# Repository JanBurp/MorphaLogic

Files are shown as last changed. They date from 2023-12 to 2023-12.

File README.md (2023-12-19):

# MorphaLogic

An Eurorack module based around a Arduino Nano.

With AND, OR, XOR logic functions, a Flip Flip (Q), a Clock Divider mode, and more.

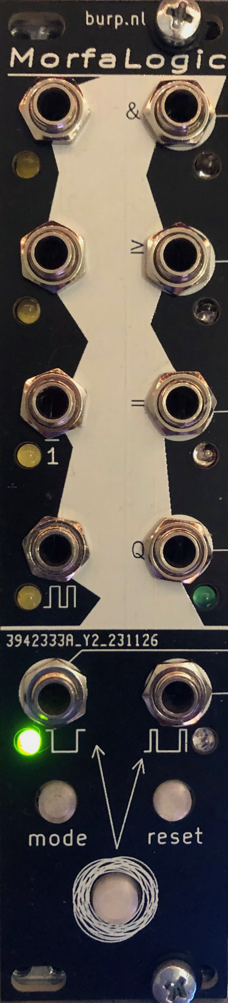
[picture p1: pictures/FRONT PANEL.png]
Morgalogic Front Panel


## Inputs, Outputs & Buttons

<table>
<tr>
<td><b>LEFT</b></td><td style="text-align: right;"><b>RIGHT</b></td>
    <tr><td>INPUT: input (A)</td><td style="text-align: right;">OUTPUT: AND (or clock / 16)</td></tr>
    <tr><td>INPUT: input (B)</td><td style="text-align: right;">OUTPUT: OR (or clock / 8)</td></tr>
    <tr><td>INPUT: Inverse (INV)</td><td style="text-align: right;">OUTPUT: XOR (or clock / 4)</td></tr>
    <tr><td>INPUT: Clock (CLK)</td><td style="text-align: right;">OUTPUT: Q - Flip Flop (or clock / 2)</td></tr>
    <tr><td>OUTPUT: Inverse of TRIG BUTTON</td><td style="text-align: right;">Trigger on press & release of TRIG BUTTON</td></tr>
    <tr><td>BUTTON: Mode button</td><td style="text-align: right;">BUTTON: Reset button</td></tr>
    <tr><td colspan="2" style="text-align: center;">TRIG BUTTON</td></tr>
</tr>
</table>

## Functions

### Logic functions

- Basic logic funcions AND, OR, XOR (using the first inputs on the left side).
- Flip Flop (Q) (first input will SET, second input will RESET).
- NOT input, or MODE button, to inverse all logic outputs (NAND, NOR, NXOR, NQ)
- CLOCK input, when present, all Logic outputs only are HIGH when CLOCK is HIGH
- RESET button to reset Q and CLOCK

### Trig button

When the TRIG button is pressed (and released):

- A LOW gate is send to the first (left) output. It will be HIGH when the button is not pressed.
- A short pulse is send to the second output on press & release of the button.
- If the module is in Clock Divider mode, the press & release time will set the Clock Tempe if no signal is present on the CLOCK input.

## Modes:

Current mode is set in memory.

### Normal mode (mode button is unlit):

- Inputs A & B determines logic outputs (AND, OR, XOR, Q). Where A is set and B is reset for the flipflop (Q).
- If the NOT input is HIGH, all logic outputs are inverted (NAND, NOR, NXOR,NQ)

### Inverse mode (mode button is lit):

- Pressing the mode button will inverse all logic outputs (same as when NOT input is HIGH)

### Clockdivider mode (mode button is flashing):

- A long press on the mode button will put the module in Clockdivider mode. The mode button will flash.
- The logic outputs will divide the clock (where Q = /2, XOR = /4, OR = /8, AND =/16)
- The clock source is:
  - The CLK input
  - If no clock is present on the CLK input, a standard 120 BPM clock is used.
  - Or, if the trig buttons has been pressed and released, the timing between press and release is used to determine the clock time.

### External Trig Mode (trig button flashes):

- A long press of the RESET button toggles between external trig options mode on/off. When on, the trig button flashes.
- When external trig mode is on, the first input can function as an external trig for the trig button.

## Uses

- Use the logic function for all kinds of GATE manipluations, for interesting sequences for example.
- Same for the CLOCK DIVIDER mode.
- Make use of the CLOCK input to quantize the logic outputs with a clock signal.
- Use the TRIG BUTTON (or external trig mode) for changing a GATE into two short TRIGS.
- Use the TRIG BUTTON to fire a LOW gate (patch it into one of the logic function to have a HIGH gate on the OR output).

### Example with a Morphagene

One of my main modules in my eurorack case is the Make-Noise Morphagene. One thing that i'd like it to do is:

- Press and hold button to record - currently playing loop is stopped, and recording is started.
- Release button - recording is stopped and starts playing.

To make this work:

- Prepare the Morphagene by setting the `Record option (rsop)` in the `options.txt` file on the SD card to '1'.
- Patch the TRIGGER output of the TRIG BUTTON to the RECORD input of the Morphagene
- Patch the INVERSE output of the TRIG BUTTOON to the PLAY input of the Morphagene

Now:

- When pressing (and holding) the TRIG BUTTON the Morphagene start recording (and stops playing).
- When releasing the TRIG BUTTON the Morphagene stops recording and starts playing.
- If in Clock Divider mode and no Clock signal is present at the CLOCK input, the tempo is set to the time between pressing and releasing the button.

# Content:

In this repo you'll find:

- Arduino program
- Schematics
- BOM
- KiCad project with schematics & PCB & FrontPanel PCB
- STL file for printing the buttons
- Several pictures

# Buying a kit

If you'd like to build this module you can buy a kit with:

- PCB
- Frontpanel
- 3D printed buttons

Contact me if you are interested.

By Jan den Besten <a href="https://www.jandenbesten.com">www.jandenbesten.com</a>

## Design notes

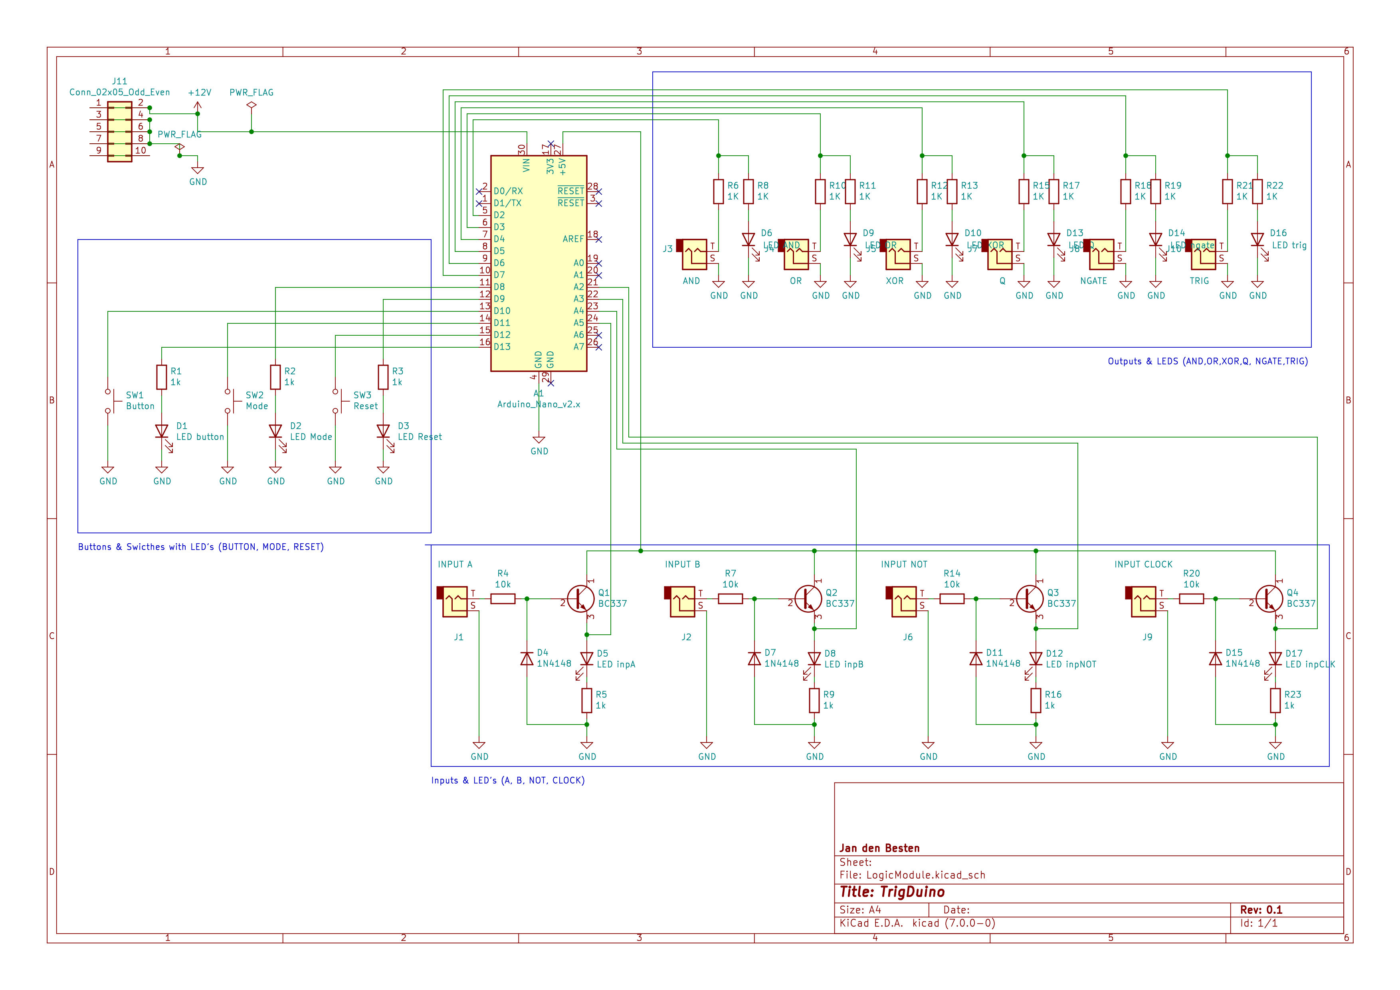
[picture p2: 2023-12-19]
schematic.png

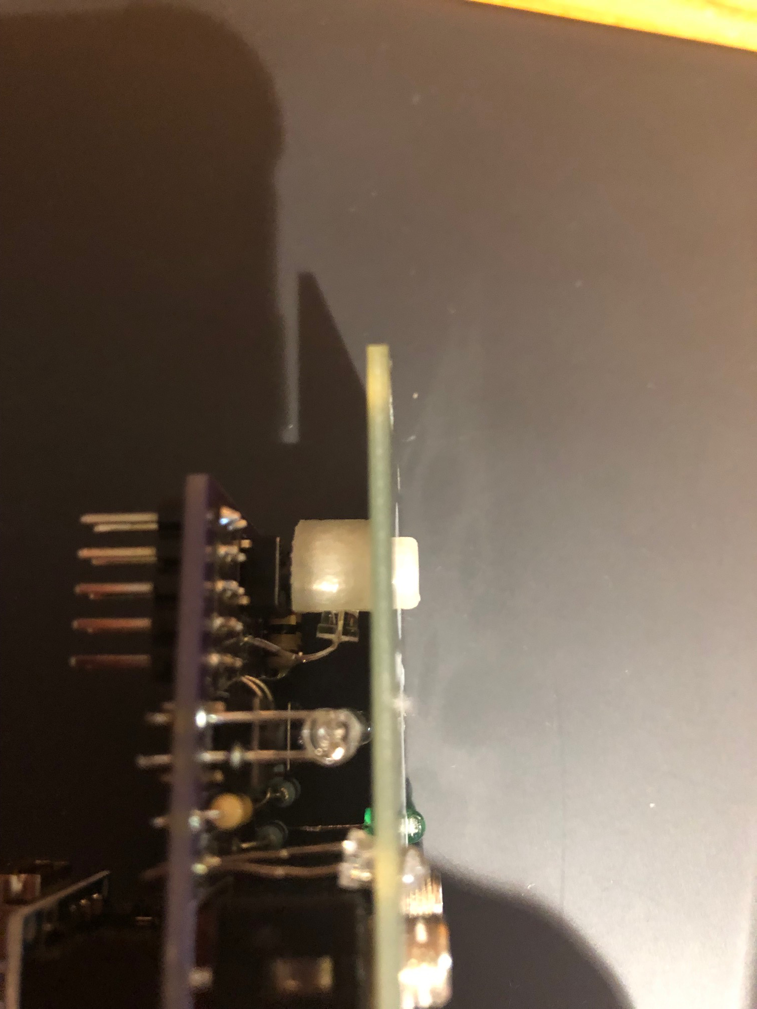
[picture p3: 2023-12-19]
docs/pictures/BUTTON DETAIL.jpg

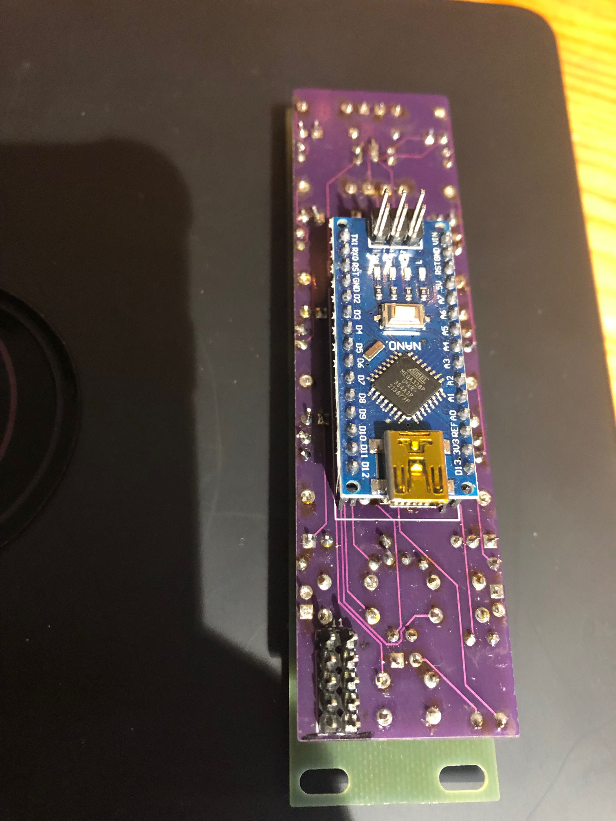
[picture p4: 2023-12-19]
docs/pictures/BACK.jpg

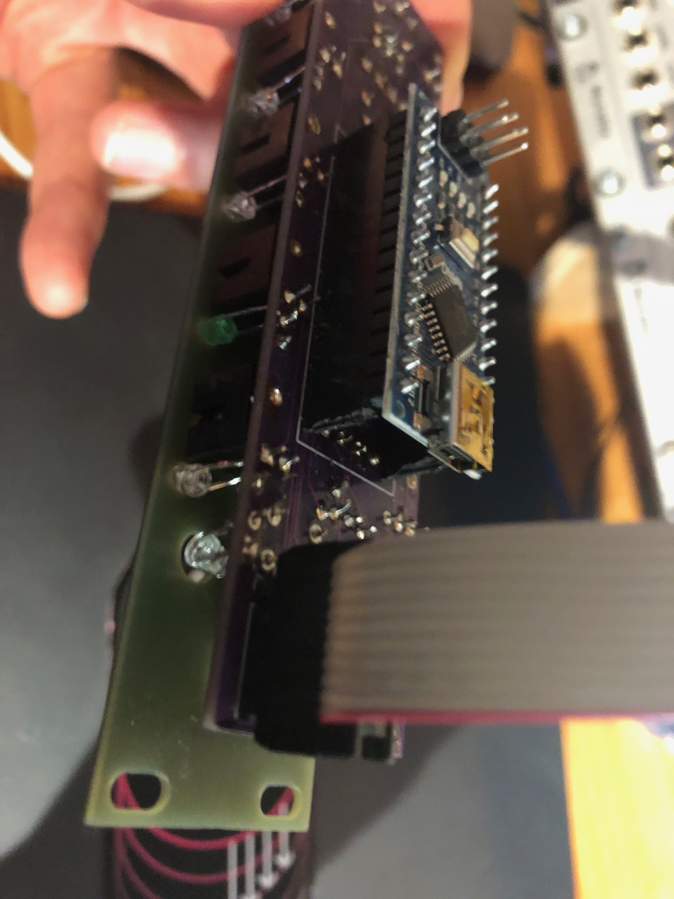
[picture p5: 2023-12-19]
docs/pictures/CONNECTING POWER.jpg

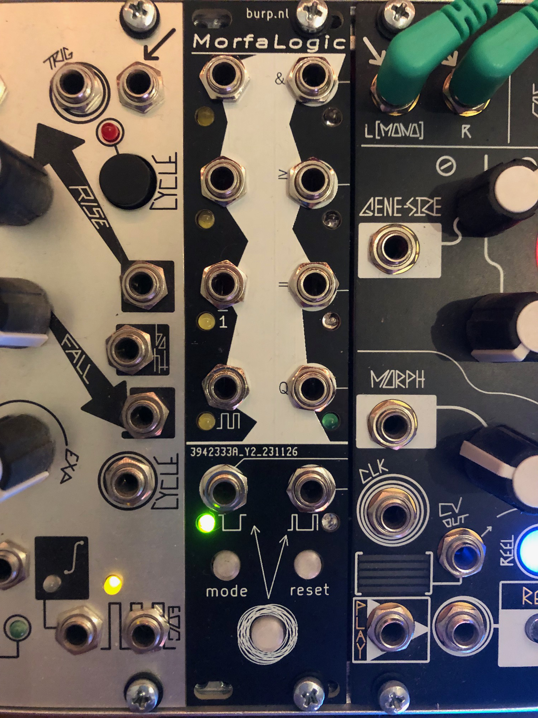
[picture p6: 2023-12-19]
docs/pictures/INSIDE RACK.jpg

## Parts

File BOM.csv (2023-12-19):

# | Reference | Qty | Value | Footprint | DNP
1 | A1 | 1 | Arduino_Nano_v2.x | Module:Arduino_Nano
2 | D1 | 1 | LED button | LED_THT:LED_D3.0mm
3 | D2 | 1 | LED Mode | LED_THT:LED_D3.0mm
4 | D3 | 1 | LED Reset | LED_THT:LED_D3.0mm
5 | D4, D7, D11, D15 | 4 | 1N4148 | Diode_THT:D_DO-35_SOD27_P7.62mm_Horizontal
6 | D5 | 1 | LED inpA | LED_THT:LED_D3.0mm
7 | D6 | 1 | LED AND | LED_THT:LED_D3.0mm
8 | D8 | 1 | LED inpB | LED_THT:LED_D3.0mm
9 | D9 | 1 | LED OR | LED_THT:LED_D3.0mm
10 | D10 | 1 | LED XOR | LED_THT:LED_D3.0mm
11 | D12 | 1 | LED inpNOT | LED_THT:LED_D3.0mm
12 | D13 | 1 | LED Q | LED_THT:LED_D3.0mm
13 | D14 | 1 | LED ngate | LED_THT:LED_D3.0mm
14 | D16 | 1 | LED trig | LED_THT:LED_D3.0mm
15 | D17 | 1 | LED inpCLK | LED_THT:LED_D3.0mm
16 | J1 | 1 | INPUT A | Connector_Audio:Jack_3.5mm_QingPu_WQP-PJ398SM_Vertical_CircularHoles
17 | J2 | 1 | INPUT B | Connector_Audio:Jack_3.5mm_QingPu_WQP-PJ398SM_Vertical_CircularHoles
18 | J3 | 1 | AND | Connector_Audio:Jack_3.5mm_QingPu_WQP-PJ398SM_Vertical_CircularHoles
19 | J4 | 1 | OR | Connector_Audio:Jack_3.5mm_QingPu_WQP-PJ398SM_Vertical_CircularHoles
20 | J5 | 1 | XOR | Connector_Audio:Jack_3.5mm_QingPu_WQP-PJ398SM_Vertical_CircularHoles
21 | J6 | 1 | INPUT NOT | Connector_Audio:Jack_3.5mm_QingPu_WQP-PJ398SM_Vertical_CircularHoles
22 | J7 | 1 | Q | Connector_Audio:Jack_3.5mm_QingPu_WQP-PJ398SM_Vertical_CircularHoles
23 | J8 | 1 | NGATE | Connector_Audio:Jack_3.5mm_QingPu_WQP-PJ398SM_Vertical_CircularHoles
24 | J9 | 1 | INPUT CLOCK | Connector_Audio:Jack_3.5mm_QingPu_WQP-PJ398SM_Vertical_CircularHoles
25 | J10 | 1 | TRIG | Connector_Audio:Jack_3.5mm_QingPu_WQP-PJ398SM_Vertical_CircularHoles
26 | J11 | 1 | Conn_02x05_Odd_Even | Connector_PinHeader_2.54mm:PinHeader_2x05_P2.54mm_Vertical
27 | Q1, Q2, Q3, Q4 | 4 | BC337 | Package_TO_SOT_THT:TO-92_Inline
28 | R1, R2, R3, R5, R9, R16, R23 | 7 | 1k | Resistor_THT:R_Axial_DIN0207_L6.3mm_D2.5mm_P10.16mm_Horizontal
29 | R4, R7, R14, R20 | 4 | 10k | Resistor_THT:R_Axial_DIN0207_L6.3mm_D2.5mm_P10.16mm_Horizontal
30 | R6, R8, R10, R11, R12, R13, R15, R17, R18, R19, R21, R22 | 12 | 1K | Resistor_THT:R_Axial_DIN0207_L6.3mm_D2.5mm_P10.16mm_Horizontal
31 | SW1 | 1 | Button | Button_Switch_THT:SW_PUSH_6mm
32 | SW2 | 1 | Mode | Button_Switch_THT:SW_PUSH_6mm
33 | SW3 | 1 | Reset | Button_Switch_THT:SW_PUSH_6mm

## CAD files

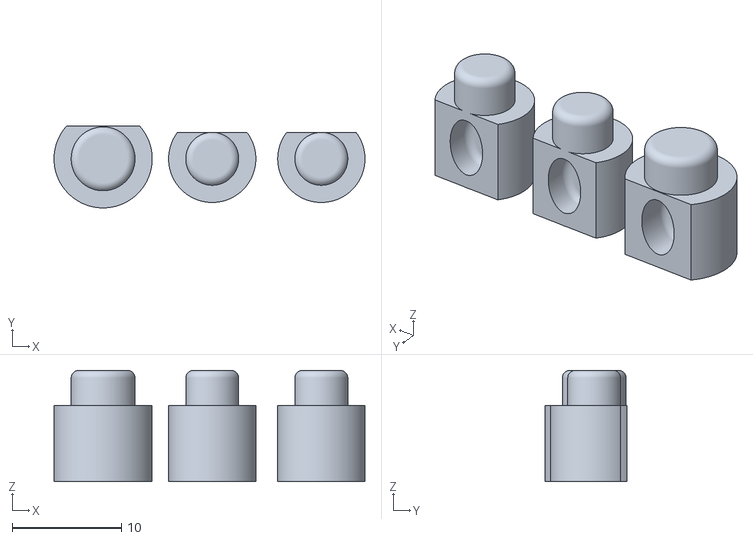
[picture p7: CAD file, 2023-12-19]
buttons/MorfButtons.stl
28.5 x 7.50 x 10.2

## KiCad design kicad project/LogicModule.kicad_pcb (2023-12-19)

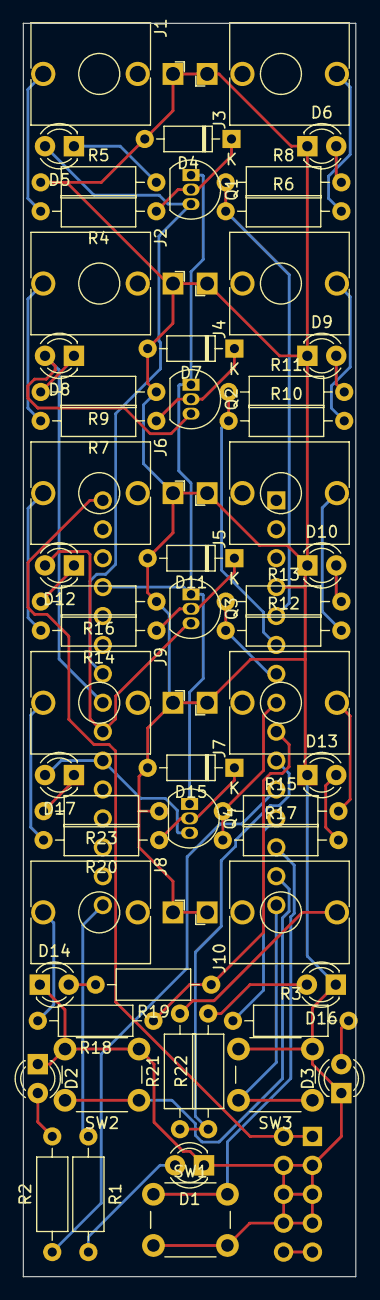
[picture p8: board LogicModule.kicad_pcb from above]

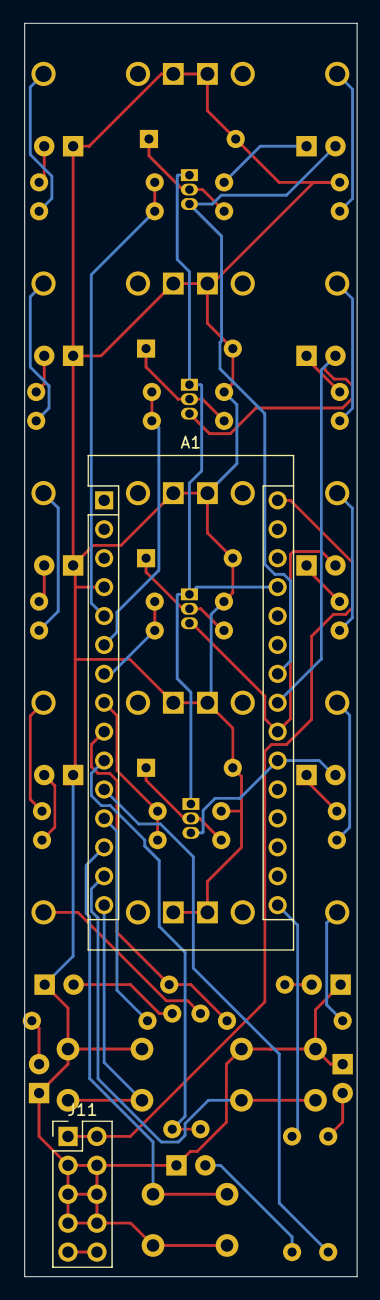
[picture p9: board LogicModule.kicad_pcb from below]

Board: 2 copper layers, 29.2 x 110.1 mm, 59 parts (2 on the bottom side), 47 nets.

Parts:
A1: Arduino_Nano_v2.x; Arduino_Nano
D1: LED button; LED_D3.0mm
D2: LED Mode; LED_D3.0mm
D3: LED Reset; LED_D3.0mm
D4, D7, D11, D15: 1N4148; D_DO-35_SOD27_P7.62mm_Horizontal
D5: LED inpA; LED_D3.0mm
D6: LED AND; LED_D3.0mm
D8: LED inpB; LED_D3.0mm
D9: LED OR; LED_D3.0mm
D10: LED XOR; LED_D3.0mm
D12: LED inpNOT; LED_D3.0mm
D13: LED Q; LED_D3.0mm
D14: LED ngate; LED_D3.0mm
D16: LED trig; LED_D3.0mm
D17: LED inpCLK; LED_D3.0mm
J1: INPUT A; Jack_3.5mm_QingPu_WQP-PJ398SM_Vertical_CircularHoles
J2: INPUT B; Jack_3.5mm_QingPu_WQP-PJ398SM_Vertical_CircularHoles
J3: AND; Jack_3.5mm_QingPu_WQP-PJ398SM_Vertical_CircularHoles
J4: OR; Jack_3.5mm_QingPu_WQP-PJ398SM_Vertical_CircularHoles
J5: XOR; Jack_3.5mm_QingPu_WQP-PJ398SM_Vertical_CircularHoles
J6: INPUT NOT; Jack_3.5mm_QingPu_WQP-PJ398SM_Vertical_CircularHoles
J7: Q; Jack_3.5mm_QingPu_WQP-PJ398SM_Vertical_CircularHoles
J8: NGATE; Jack_3.5mm_QingPu_WQP-PJ398SM_Vertical_CircularHoles
J9: INPUT CLOCK; Jack_3.5mm_QingPu_WQP-PJ398SM_Vertical_CircularHoles
J10: TRIG; Jack_3.5mm_QingPu_WQP-PJ398SM_Vertical_CircularHoles
J11: Conn_02x05_Odd_Even; PinHeader_2x05_P2.54mm_Vertical
Q1, Q2, Q3, Q4: BC337; TO-92_Inline
R1, R2, R3, R5, R9, R16, R23: 1k; R_Axial_DIN0207_L6.3mm_D2.5mm_P10.16mm_Horizontal
R4, R7, R14, R20: 10k; R_Axial_DIN0207_L6.3mm_D2.5mm_P10.16mm_Horizontal
R6, R8, R10, R11, R12, R13, R15, R17, R18, R19, R21, R22: 1K; R_Axial_DIN0207_L6.3mm_D2.5mm_P10.16mm_Horizontal
SW1: Button; SW_PUSH_6mm
SW2: Mode; SW_PUSH_6mm
SW3: Reset; SW_PUSH_6mm

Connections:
+12V: A1.30, J11.1, J11.2
GND: A1.4, D1.1, D2.1, D3.1, D4.2, D6.1, D7.2, D9.1, D10.1, D11.2, D13.1, D14.1, D15.2, D16.1, J1.S, J2.S, J3.S, J4.S, J5.S, J6.S, J7.S, J8.S, J9.S, J10.S, J11.3, J11.4, J11.5, J11.6, J11.7, J11.8, R5.1, R9.1, R16.1, R23.1, SW1.2, SW2.2, SW3.2
unnamed: A1.5, R6.1, R8.1
unnamed: A1.6, R10.1, R11.1
unnamed: A1.7, R12.1, R13.1
unnamed: A1.8, R15.1, R17.1
unnamed: A1.9, R18.1, R19.1
unnamed: A1.10, R21.1, R22.1
unnamed: A1.11, R2.1
unnamed: A1.12, R3.1
unnamed: A1.13, SW1.1
unnamed: A1.14, SW2.1
unnamed: A1.15, SW3.1
unnamed: A1.16, R1.1
unnamed: A1.21, D17.2, Q4.3
unnamed: A1.22, D12.2, Q3.3
unnamed: A1.23, D8.2, Q2.3
unnamed: A1.24, D5.2, Q1.3
unnamed: A1.27, Q1.1, Q2.1, Q3.1, Q4.1
unnamed: D1.2, R1.2
unnamed: D2.2, R2.2
unnamed: D3.2, R3.2
unnamed: D4.1, Q1.2, R4.1
unnamed: D5.1, R5.2
unnamed: D6.2, R8.2
unnamed: D7.1, Q2.2, R7.1
unnamed: D8.1, R9.2
unnamed: D9.2, R11.2
unnamed: D10.2, R13.2
unnamed: D11.1, Q3.2, R14.1
unnamed: D12.1, R16.2
unnamed: D13.2, R17.2
unnamed: D14.2, R19.2
unnamed: D15.1, Q4.2, R20.1
unnamed: D16.2, R22.2
unnamed: D17.1, R23.2
unnamed: J1.T, R4.2
unnamed: J2.T, R7.2
unnamed: J3.T, R6.2
unnamed: J4.T, R10.2
unnamed: J5.T, R12.2
unnamed: J6.T, R14.2
unnamed: J7.T, R15.2
unnamed: J8.T, R18.2
unnamed: J9.T, R20.2
unnamed: J10.T, R21.2
unnamed: J11.9, J11.10

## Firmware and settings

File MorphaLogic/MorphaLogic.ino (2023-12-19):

/**
 * 
 * MorphaLogic
 * 
 * An Eurorack module based around a Arduino Nano with:
 * 
 *  - Basic logic funcions AND, OR, XOR
 *  - Flip Flop (Q)
 *  - NOT button and NOT input to inverse all logic outputs (NAND, NOR, NXOR, NQ)
 *  - CLOCK input, when present, all Logic outputs only are HIGH when CLOCK is HIGH
 *  - RESET button to reset Q and CLOCK
 *  - Trig button and two outputs to control a MakeNoise Morphagene (PLAY and REC outputs)
 *  
 *  - Each in and outputs has its corresponding LED to show its status.
 *  - Also for each button.
 *
 * How does it work:
 *
 * - Normal mode:
 *     - Inputs A & B determines logic outputs (AND, OR, XOR, Q). Where A is set and B is reset for the flipflop (Q).
 *     - If the NOT input is HIGH, all logic outputs are inverted (NAND, NOR, NXOR,NQ)
 *     - PLAY output is HIGH. Except during a press on the trig button.
 *     - Every change of the trig button (on->off, or off->on) makes the REC output flash shortly.
 *
 * - Inverse mode:
 *     - Pressing the mode button will inverse all logic outputs (same as when NOT input is HIGH)
 *
 * - Clockdivider mode:
 *     - A long press on the mode button will put the module in Clockdivider mode. The mode button will flash.
 *     - The logic outputs will divide the clock (where Q = /2, XOR = /4, OR = /8, AND =/16)
 *     - The clock source is:
 *         - The CLK input
 *         - If no clock is present on the CLK input, a standard 120 BPM clock is used.
 *         - Or, if the trig buttons has been pressed and released, the timing between press and release is used to determine the clock time.
 *
 * - External trig mode:
 *     - A long press of the RESET button switches the external trig options on/off. When on, the trih button flashes.
 *     - The Trig button functions the same in both modes.
 *     - But when external trig mode is on, input A functions as an external trig button
 *
 *
 * Both mode settings are stored in memory.
 *
 *
 *  (c) Jan den Besten
 * 
 */

#define DEBUG false

#include <EEPROM.h>

#include "lib/Input.cpp"
#include "lib/Button.cpp"
#include "lib/Output.cpp"


/**
 * PINS
 */

#define INPUT_A             19  // A5
#define INPUT_B             18  // A4
#define INPUT_NOT           17  // A3
#define INPUT_CLK           16  // A2

#define BUTTON_MODE         11  // LEFT BUTTON
#define BUTTON_RESET        12  // RIGHT BUTTON
#define BUTTON_TRIG         10  // MAIN BUTTON

#define OUTPUT_AND          2
#define OUTPUT_OR           3
#define OUTPUT_XOR          4
#define OUTPUT_Q            5
#define OUTPUT_PLAY         6
#define OUTPUT_REC          7

#define LED_BUTTON_TRIG     13
#define LED_BUTTON_MODE     8
#define LED_BUTTON_RESET    9

/**
 * MODES
 */
#define LOGIC               0
#define INVERSE             1
#define CLOCKDIVIDER        2

#define NORMAL_TRIG         1
#define EXTERNAL_TRIG       2

/**
 * TIMINGS
 */
#define LONG_BUTTON_PRESS   1000        // Time to press a button to trigger the long press function
#define RESET_CLOCK_DELAY   2000        // Time to reset clock input


byte ClockDivisions[4] = { 1,2,4,8 };


struct STATE {

    // inputs
    Input inputA;
    Input inputB;
    Input inputNOT;
    Input inputCLK;

    // buttons
    Button buttonMODE;
    Button buttonRESET;
    Button buttonTRIG;

    // states
    bool A;
    bool prevA;
    bool B;
    bool NOT;
    bool CLK;
    bool MODE_BUTTON;
    bool RESET_BUTTON;
    bool TRIG_BUTTON;
    bool Q;

    // mode
    byte prevMode;
    byte mode;

    // clock
    bool hasClock;
    bool clockIsRunning;
    bool prevClock;
    bool risingClock;
    bool fallingClock;
    int ticks[4];

    // timings
    unsigned long startPeriod;
    unsigned long clockPeriod;
    unsigned long startLoopPeriod;
    unsigned long loopPeriod;

    // trigger modes
    bool prevTrig;
    byte trigMode;
    byte prevTrigMode;

} State;


struct OUTPUTS {

    // outputs
    Output AND;
    Output OR;
    Output XOR;
    Output Q;
    Output PLAY;
    Output REC;

    // LEDS
    Output mode;
    Output reset;
    Output trig;

} Outputs;



/**
 * 
 * ==== SETUP ====
 * 
 */

void setup() {
    if (DEBUG) Serial.begin(9600);

    // state input pins
    State.inputA.init( INPUT_A );
    State.inputB.init( INPUT_B );
    State.inputNOT.init( INPUT_NOT );
    State.inputCLK.init( INPUT_CLK );
    State.buttonMODE.init( BUTTON_MODE );
    State.buttonRESET.init( BUTTON_RESET );
    State.buttonTRIG.init( BUTTON_TRIG );

    // state defaults
    State.A = false;
    State.prevA = false;
    State.B = false;
    State.NOT = false;
    State.CLK = false;
    State.MODE_BUTTON = false;
    State.RESET_BUTTON = false;
    State.TRIG_BUTTON = false;
    State.Q = false;

    State.prevMode = LOGIC;
    // State.mode = LOGIC;
    EEPROM.get(0, State.mode);

    State.clockIsRunning = false;
    State.prevClock = false;
    State.risingClock = false;
    State.fallingClock = false;
    State.startPeriod = 0;
    State.clockPeriod = 500; // 120bpm

    State.prevTrig = false;
    State.prevTrigMode = NORMAL_TRIG;
    // State.trigMode = NORMAL_TRIG;
    EEPROM.get(1, State.trigMode);
    State.startLoopPeriod = 0;
    State.loopPeriod = 0;

    // output pins
    Outputs.AND.init( OUTPUT_AND );
    Outputs.OR.init( OUTPUT_OR );
    Outputs.XOR.init( OUTPUT_XOR );
    Outputs.Q.init( OUTPUT_Q );
    Outputs.PLAY.init( OUTPUT_PLAY );
    Outputs.REC.init( OUTPUT_REC );
    // led pins
    Outputs.mode.init( LED_BUTTON_MODE );
    Outputs.reset.init( LED_BUTTON_RESET );
    Outputs.trig.init( LED_BUTTON_TRIG );
}


/**
 * Read's inputs & buttons
 * And prepare states
 */
void setState() {

    State.A = State.inputA.read();
    State.B = State.inputB.read();
    State.NOT = State.inputNOT.read();
    State.CLK = State.inputCLK.read();
    State.MODE_BUTTON = State.buttonMODE.read();
    State.RESET_BUTTON = State.buttonRESET.read();
    State.TRIG_BUTTON = State.buttonTRIG.read();

    // Mode
    byte currentMode = State.mode;
    if ( State.buttonMODE.readOnce() ) {
        if ( State.mode == LOGIC ) {
            State.mode = INVERSE;
        }
        else {
            State.mode = LOGIC;
        }
    }
    if ( State.buttonMODE.readLongPressOnce(LONG_BUTTON_PRESS) ) {
        State.mode = CLOCKDIVIDER;
    }
    // Keep in memory if changed
    if (currentMode!=State.mode) {
        EEPROM.write(0, State.mode);
    }

    // Reset
    if ( State.RESET_BUTTON == HIGH ) {
        State.hasClock = false;
        State.clockIsRunning = false;
    }

    // Clock
    State.risingClock = ( State.CLK==HIGH && State.prevClock==LOW );
    State.fallingClock = ( State.CLK==LOW && State.prevClock==HIGH );
    if ( State.risingClock ) {
        if (State.startPeriod > 0) {
            State.clockPeriod = millis() - State.startPeriod;
            State.hasClock = true;
        }
        State.startPeriod = millis();
    }
    if ( State.CLK==LOW && millis()-State.startPeriod > RESET_CLOCK_DELAY ) {
        State.hasClock = false;
    }

    State.prevClock = State.CLK;


    // Trig & Loop timing
    if ( State.prevTrig==false && State.TRIG_BUTTON==true) {
        State.startLoopPeriod = millis();
    }
    if ( State.prevTrig==true && State.TRIG_BUTTON==false) {
        State.loopPeriod = millis() - State.startLoopPeriod;
        State.startLoopPeriod = 0;
    }

    // Trigmode
    if ( State.buttonRESET.readLongPressOnce(LONG_BUTTON_PRESS) ) {
        if ( State.trigMode == NORMAL_TRIG ) {
            State.trigMode = EXTERNAL_TRIG;
        }
        else {
            State.trigMode = NORMAL_TRIG;
        }
    }
    // Keep in memory if changed
    if ( State.trigMode != State.prevTrigMode ) {
        EEPROM.write(1, State.trigMode );
    }


}

/**
 * Set button LED's according to state
 */
void buttonLEDS() {
    if (DEBUG) {
        Serial.print("Mode:");
        switch ( State.mode ) {
            case LOGIC:
                Serial.print("LOGIC           CLK: "); Serial.print( State.hasClock ); Serial.print(" RUNNING: "); Serial.println(State.clockIsRunning);
                break;
            case INVERSE:
                Serial.print("INVERSE         CLK: "); Serial.print( State.hasClock ); Serial.print(" RUNNING: "); Serial.println(State.clockIsRunning);
                break;
            case CLOCKDIVIDER:
                Serial.print("CLOCKDIVIDER    CLK: "); Serial.print( State.hasClock ); Serial.print(" RUNNING: "); Serial.println(State.clockIsRunning);
                break;
        }
    }

    // Mode
    if ( State.mode != State.prevMode ) {
        switch ( State.mode ) {
            case LOGIC:
                Outputs.mode.off();
                break;
            case INVERSE:
                Outputs.mode.on();
                break;
            case CLOCKDIVIDER:
                Outputs.mode.blink(500);
                break;
        }
    }
    State.prevMode = State.mode;

    // Reset
    Outputs.reset.set( State.RESET_BUTTON );

    // Trig
    if ( State.trigMode == EXTERNAL_TRIG ) {
        if ( State.trigMode != State.prevTrigMode ) {
            Outputs.trig.blink(500);
        }
    }
    else {
        Outputs.trig.set( State.TRIG_BUTTON );
    }
    State.prevTrigMode = State.trigMode;
}


/**
 * Determine clockdividers outputs
 */
void ClockDivider() {

    // Reset
    if ( !State.clockIsRunning || State.RESET_BUTTON==HIGH ) {
        Outputs.AND.off();
        Outputs.OR.off();
        Outputs.XOR.off();
        Outputs.Q.off();
        State.clockIsRunning = false;
    }

    // No clock & loop - just start with default clock
    if ( !State.hasClock && State.loopPeriod==0 && State.TRIG_BUTTON==LOW ) {
        if ( !State.clockIsRunning ) {
            State.clockIsRunning = true;
            SetClockTicks( State.clockPeriod );
        }
    }

    // Use Loop timing
    if ( !State.hasClock && State.loopPeriod!=0 ) {
        if ( !State.clockIsRunning ) {
            State.clockIsRunning = true;
            SetClockTicks( State.loopPeriod );
        }
    }

    // Normal clock divider with CLK input
    if ( State.hasClock ) {
        if ( State.risingClock ) {
            // Start
            if ( !State.clockIsRunning ) {
                State.clockIsRunning = true;
                for (int i = 0; i < 4; ++i)
                {
                    State.ticks[i] = 0;
                }
            }
            else {
                for (int i = 0; i < 4; ++i)
                {
                    State.ticks[i] += 1;
                }
            }
            // Show
            if ( State.ticks[0] / ClockDivisions[0] == 1 ) { Outputs.Q.toggle(); State.ticks[0] = 0; }
            if ( State.ticks[1] / ClockDivisions[1] == 1 ) { Outputs.XOR.toggle(); State.ticks[1] = 0; }
            if ( State.ticks[2] / ClockDivisions[2] == 1 ) { Outputs.OR.toggle(); State.ticks[2] = 0; }
            if ( State.ticks[3] / ClockDivisions[3] == 1 ) { Outputs.AND.toggle(); State.ticks[3] = 0; }
        }
    }
}

void SetClockTicks(unsigned long period) {
    Outputs.Q.blink( period * ClockDivisions[0] );
    Outputs.XOR.blink( period * ClockDivisions[1] );
    Outputs.OR.blink( period * ClockDivisions[2] );
    Outputs.AND.blink( period * ClockDivisions[3] );
}


/**
 * Determine logic outputs
 */
void Logic() {
    bool AND = (State.A && State.B);
    bool OR = (State.A || State.B);
    bool XOR = (State.A != State.B);

    if ( State.mode == INVERSE || State.NOT == true ) {
        AND =  ! AND;
        OR  =  ! OR;
        XOR =  ! XOR;
    }

    if ( State.hasClock ) {
        AND = State.CLK && AND;
        OR  = State.CLK && OR;
        XOR = State.CLK && XOR;
    }

    Outputs.AND.set( AND );
    Outputs.OR.set( OR );
    Outputs.XOR.set( XOR );
}


/**
 * Determine FlipFlop output
 */
void FlipFlop() {
    if ( State.hasClock ) {
        if ( State.CLK == HIGH ) {
            if ( State.TRIG_BUTTON || State.A) {
                State.Q = true;
            }
            if ( State.RESET_BUTTON || State.B ) {
                State.Q = false;
            }
        }
    }
    else {
        if ( State.TRIG_BUTTON || State.A) {
            State.Q = true;
        }
        if ( State.RESET_BUTTON || State.B ) {
            State.Q = false;
        }
    }

    if ( State.mode == INVERSE || State.NOT == true ) {
        Outputs.Q.set( !State.Q );
    }
    else {
        Outputs.Q.set( State.Q );
    }
}

/**
 * Deterime Morphagene control
 */
void Morphagene() {
    if ( State.TRIG_BUTTON || (State.trigMode == EXTERNAL_TRIG && State.A) ) {
        Outputs.PLAY.off();
        if ( !State.hasClock ) {
            State.clockIsRunning = false;
        }
    }
    else {
        Outputs.PLAY.on();
    }

    if ( State.TRIG_BUTTON != State.prevTrig || (State.trigMode == EXTERNAL_TRIG && State.A != State.prevA )) {
        Outputs.REC.flash();
        State.prevTrig = State.TRIG_BUTTON;
    }
    State.prevA = State.A;
}



/**
 * Loop all outputs (for blinking etc)
 */
void loopOutputs() {
    // Outputs
    Outputs.AND.loop();
    Outputs.OR.loop();
    Outputs.XOR.loop();
    Outputs.Q.loop();
    Outputs.PLAY.loop();
    Outputs.REC.loop();
    // LEDS
    Outputs.mode.loop();
    Outputs.reset.loop();
    Outputs.trig.loop();
}

/**
 *
 * ==== MAIN LOOP ====
 *
 */

void loop() {

    setState();
    buttonLEDS();
    Morphagene();

    if (State.mode==CLOCKDIVIDER) {
        ClockDivider();
    }
    else {
        Logic();
        FlipFlop();
    }

    loopOutputs();
}

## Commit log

2021-07-07 commit basics
    [MorphaLogic.stl]
2023-12-19 adding arduino code as submodule
2023-12-19 added schematic
2023-12-19 Adding BOM & KiCad
    [BOM.csv, LogicModule.csv, LogicModule.kicad_pcb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]
2023-12-19 adding 3D buttons
    [MorfButtons.stl]
